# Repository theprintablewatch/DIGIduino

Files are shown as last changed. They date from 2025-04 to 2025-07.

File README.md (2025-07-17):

# The Printable Watch Digital 
Check out [TPW](https://theprintablewatch.com)

Kickstarter Campaign [Kickstarter](https://www.kickstarter.com/projects/theprintablewatch/digiduino-arduino-based-diy-digital-watch-development-kit)

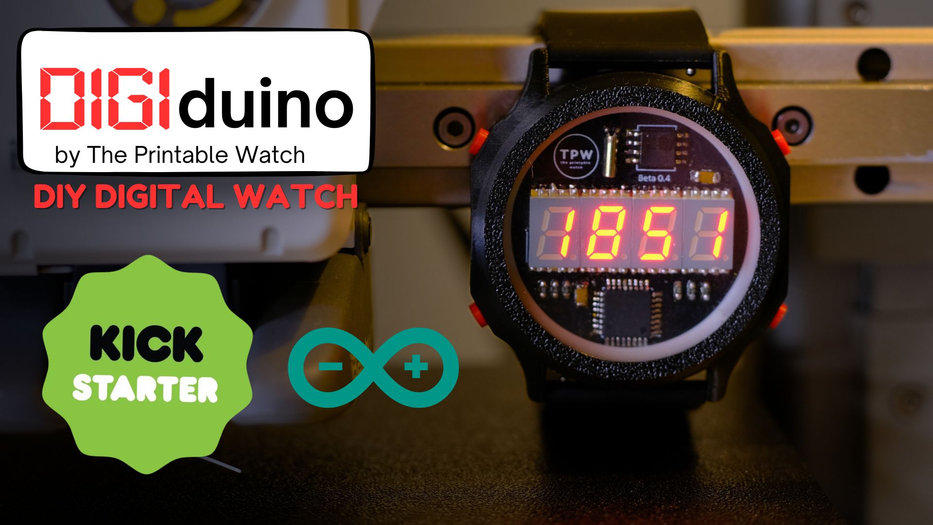
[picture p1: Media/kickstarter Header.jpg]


## Features
  * Arduino based digital watch
    * ATMega328P based
    * DS1302 RTC
    * 4 Digit 7-segment display
    * 4 Programmable physical buttons
  * 3D printed watch case
  * 12 Month+ Battery life

## Arduino Requirements
 * Libraries Used:
   * SevSeg - Dean Reading - https://github.com/DeanIsMe/SevSeg
   * Rtc by Makuna - Michael C. Miller - https://github.com/Makuna/Rtc/wiki
   * MiniCore - MCUdude - https://github.com/MCUdude/MiniCore
      * Add this link to your Boards Manager under Preferences - https://mcudude.github.io/MiniCore/package_MCUdude_MiniCore_index.json

## 3D Printable Case

The case and pushbuttons are designed to be easily 3D printed from any standard 3D printer. I have made the .STEP files available as well as a .dxf of the PCB so you can modify the case or even design your own!
[Download Case Models](https://github.com/theprintablewatch/DIGIduino/tree/main/Models)
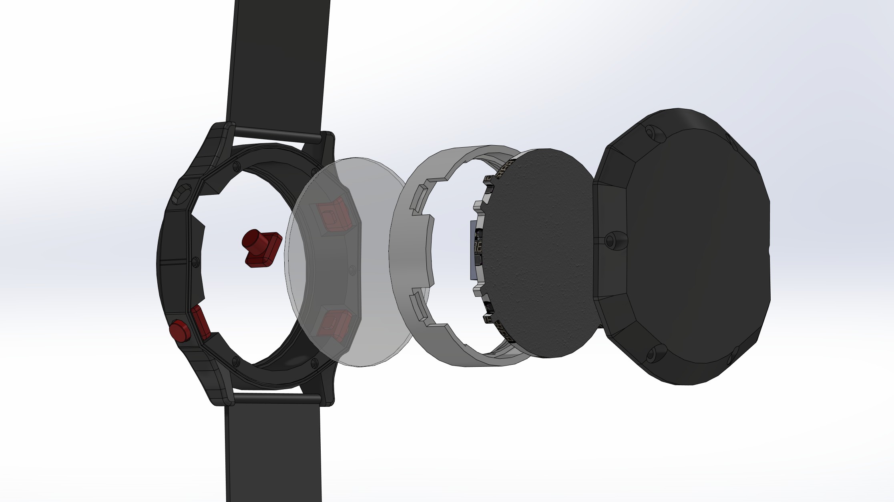
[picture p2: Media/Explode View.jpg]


## How to use the watch?

DIGIduino - How to use the watch? (https://youtu.be/XvohYlr38eU)

## How to Program ATMega328

Follow the guide [here](https://github.com/theprintablewatch/DIGIduino/blob/541a8b5c67f3c3e3cfa8df9d08a5a50cb2cadccd/Programming%20Guide.MD)

I have also filmed a short youtube video explaining how to program a ATMega328 seperate from the Uno more generally.

Minimalist Arduino - How to Program ATmega328 and ATtiny85 (https://youtu.be/qGbuzuVSzVs)

To program the chip on the PCB, follow these steps using the JST Jumper cable

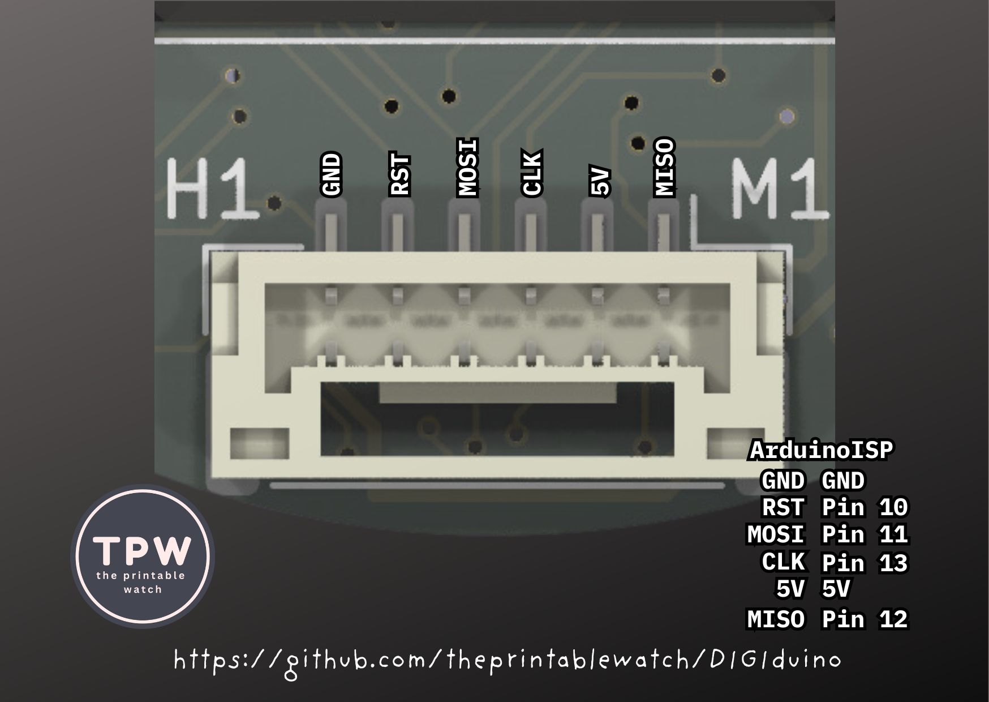
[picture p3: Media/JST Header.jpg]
Back Board


## Developing your own firmware

The DIGIduino firmware is open source, I encourage you to make a copy of the basic firmware and add your own features!
Pins used:

## 🔌 Pin Usage Summary

| **Pin** | **Arduino Alias** | **Function** |
|---|---|---|
| **0** | `D0` | Top Left Button |
| **1** | `D1` | SevSeg digit 0 control |
| **2** | `D2` | Top Right Button (Wake-up button) |
| **3** | `D3` | SevSeg digit 1 control |
| **4** | `D4` | SevSeg digit 2 control |
| **5** | `D5` | SevSeg digit 3 control |
| **6** | `D6` | SevSeg segment A |
| **7** | `D7` | SevSeg segment B |
| **8** | `D8` | SevSeg segment C |
| **9** | `D9` | SevSeg segment D |
| **10**  | `D10` | SevSeg segment E |
| **11**  | `D11` | SevSeg segment F |
| **12**  | `D12` | SevSeg segment G |
| **13**  | `D13` | SevSeg segment DP (decimal point) |
| **14**  | `A0` | RTC Data I/O (`ThreeWire` – DS1302) |
| **15**  | `A1` | RTC CLK (SCLK) |
| **16**  | `A2` | RTC CE (RST) |
| **17**  | `A3` | RTC Power Pin (set HIGH in `isrWake`, LOW in `goToSleep`) |
| **18**  | `A4` | Low Left Button |
| **19**  | `A5` | Low Right Button |
| **20**  | `20` | Spare - Disabled (`pinMode(20, OUTPUT)`) |
| **21**  | `21` | Spare - Disabled (`pinMode(21, OUTPUT)`) |
| **22**  | `22` | Spare - Disabled (`pinMode(22, OUTPUT)`) |

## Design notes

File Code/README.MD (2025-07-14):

Full set-up instructions [here](https://github.com/theprintablewatch/DIGIduino/blob/main/Programming%20Guide.MD)

Before you start, add the MCUdude MiniCore board package to your directories.
File > Preferences - Additional boards manager URLs: > paste this link https://mcudude.github.io/MiniCore/package_MCUdude_MiniCore_index.json

Make sure to follow the programmin
  * SevSeg - Dean Reading
  * Rtc by Makuna - Micheael C. Miller

## Key Features and Libraries

The DIGIduino is an Arduino‑based digital watch built around:
- **ATmega328P** microcontroller
- **DS1302** real‑time clock (RTC)
- **Four-digit seven-segment display**
- **Four control buttons**

### Required Libraries
- [`SevSeg`](https://github.com/DeanIsMe/SevSeg)
- [`Rtc by Makuna`](https://github.com/Makuna/Rtc)

---

## Main Firmware File

The main sketch is located at:

Code/DIGIduinoV1/DIGIduinoV1.ino

The firmware uses a small **state machine** to manage different watch modes:

```c++
// ------------------ State Machine ------------------
enum WatchState {
  NORMAL,
  SHOWDATE,
  SHOWSET,
  TIMESET,
  SHOWDSET,
  DATESET,
  YEARSET,
  UKUSSET,
  SLEEPING
};
```

### Setup Function

The setup() function does the following:
 - Configures button pins
 - Attaches a wake-up interrupt
 - Initializes the seven-segment display
 - Starts the real-time clock
 - Loop and State Machine

The loop() function continuously refreshes the display and switches between states:

```c++
// Refresh the display often
sevseg.refreshDisplay();

// State machine
switch(watchState)
{
  case NORMAL:
    handleNormalMode();
    break;
  case SHOWDATE:
    handleShowDateMode();
    break;
  // ... other cases
  case SLEEPING:
    // Nothing to do while asleep
    break;
}
```

### Example Mode: Normal Operation
handleNormalMode() handles standard time display and input:

```c++
// Time is read once globally to reduce flickering
sevseg.setNumber(timeCombined);

// Check for inactivity → sleep
if(currentMillis - lastInteraction > wakeInterval) {
  goToSleep();
  return;
}

// Handle Spare Pin (enter time-set if held 2s)
checkSparePinHold();
checkHourPinHold();
```

### Sleep and Wake

When idle, the watch enters low power sleep mode:
`pin 17` is the power pin to the RTC, setting this high and low can switch the RTC on and off. Note when the RTC is in sleep it will still keep track of time but it's not possible to set or read the time.

`digitalWrite(17, LOW)` puts the RTC to sleep

```c++
void goToSleep()
{
  // Blank display & reduce power
  sevseg.blank();
  sevseg.refreshDisplay();
  digitalWrite(17, LOW);
  watchState = SLEEPING;

  // Enter AVR power-down mode
  ADCSRA &= ~(1 << 7);
  SMCR |= (1 << 2);
  SMCR |= 1;
  MCUCR |= (3 << 5);
  MCUCR = (MCUCR & ~(1 << 5)) | (1 << 6);
  __asm__ __volatile__("sleep");
}
```

Waking is triggered by a button interrupt:
`digitalWrite(17, HIGH)` Wakes the RTC

```c++
void isrWake()
{
  wakeInterruptTriggered = true;
  digitalWrite(17, HIGH);
  watchState = NORMAL;

  now = Rtc.GetDateTime();
  hour = now.Hour();
  minute = now.Minute();
  day = now.Day();
  month = now.Month();
  year = now.Year();

  lastInteraction = millis();
}
```

## Getting Started

Install the MiniCore board package and required libraries (see README.md and Programming Guide.MD).
Open DIGIduinoV1.ino in the Arduino IDE.
Review the state machine and handlers.
Try modifying handleShowDateMode() or add a new watch mode.
Use HardwareTest/HardwareTest.ino to test buttons and display.

## Firmware Architecture Summary
The firmware is structured with:
Initialization in setup()
A state machine in loop()
Dedicated handler functions for each mode
This clean separation makes it easy to understand and extend. Once you're comfortable with how state transitions and display updates work, you can start adding custom watch features.

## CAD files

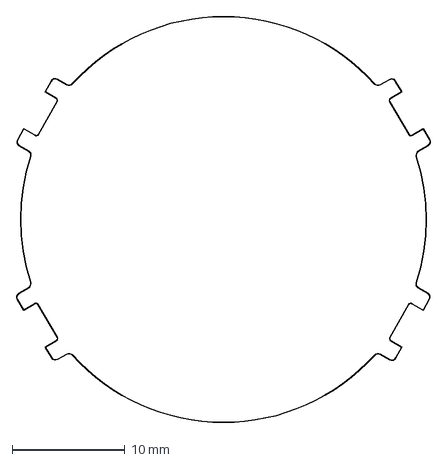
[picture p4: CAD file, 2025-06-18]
Models/PCB Shape2.DXF
36.8 x 36.1 mm

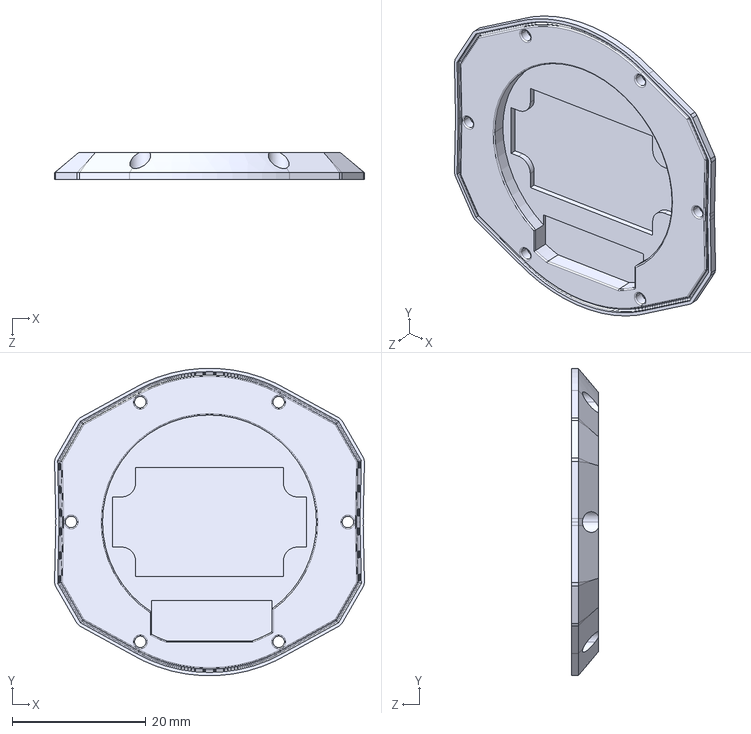
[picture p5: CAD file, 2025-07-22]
Models/VersionA/DigiDuinoV1 Caseback.STEP
46.4 x 45.9 x 4.00 mm

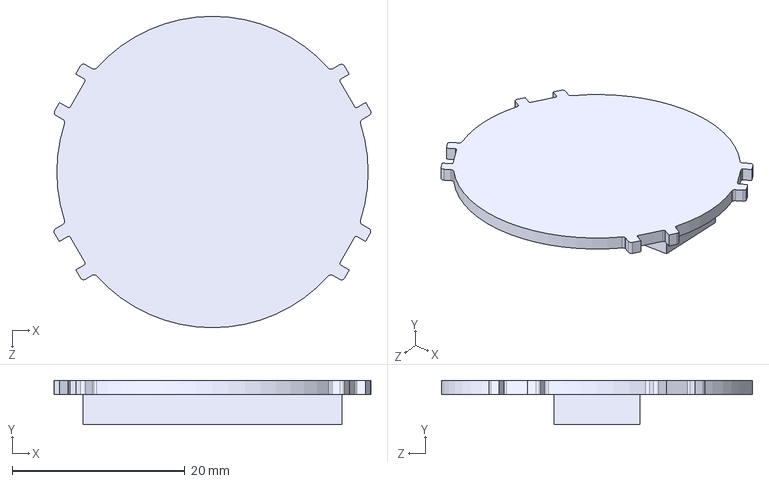
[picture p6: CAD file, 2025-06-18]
Models/PCB Shape.STEP
36.7 x 5.10 x 36.1 mm

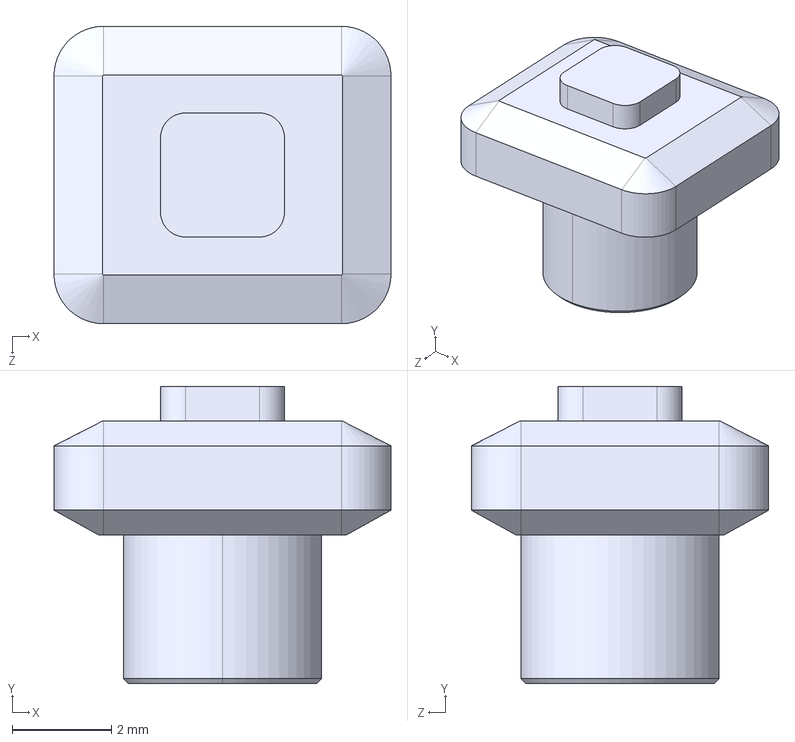
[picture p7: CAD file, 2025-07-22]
Models/VersionA/DigiDuinoV1 Button.STEP
6.80 x 6.00 x 6.00 mm

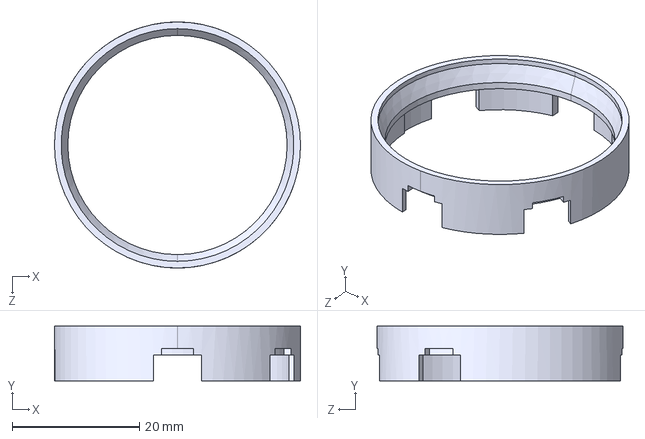
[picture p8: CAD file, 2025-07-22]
Models/VersionA/DigiDuinoV1 Insert Universal.STEP
38.6 x 8.60 x 38.6 mm

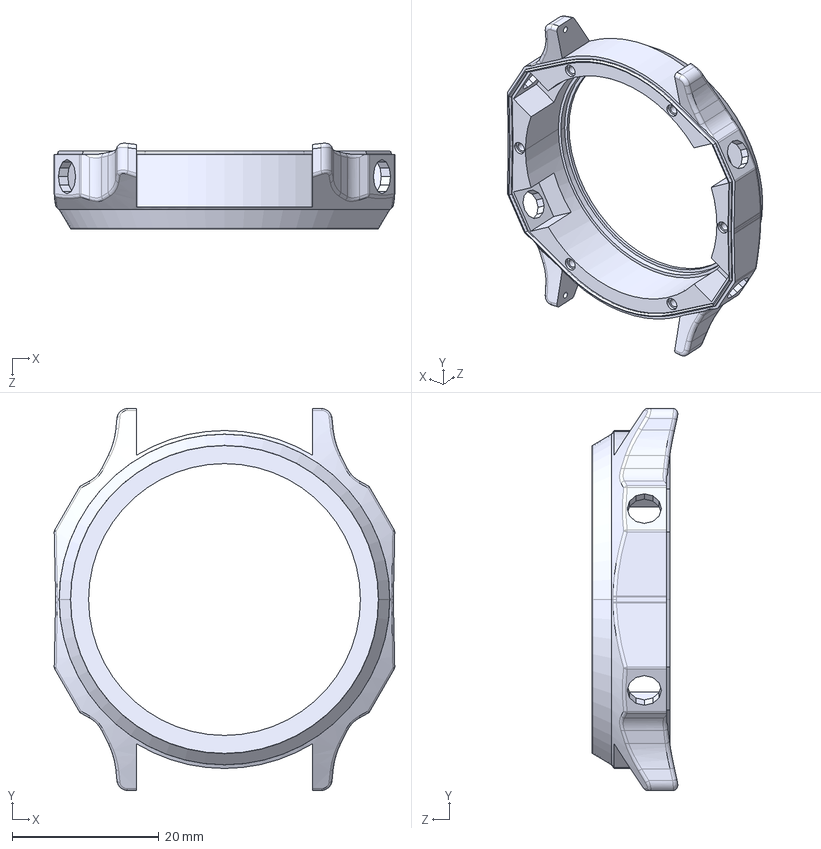
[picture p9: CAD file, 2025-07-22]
Models/VersionA/DigiDuinoV1 Case.STEP
46.4 x 52.0 x 11.7 mm

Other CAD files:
Models/PCB Shape.STL
Models/VersionA/DigiDuinoV1 Button.STL
Models/VersionA/DigiDuinoV1 Case.STL
Models/VersionA/DigiDuinoV1 Caseback.STL
Models/VersionA/DigiDuinoV1 Insert Universal.STL

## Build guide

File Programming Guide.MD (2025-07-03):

# How to program your DIGIduino

### You will need
  * Arduino UNO
  * Programmer Shield 
  * JST Cable
  * Arduino IDE installed on your device

## Step 1

### Arduino IDE setup

Before you start, add the MCUdude MiniCore board package to your directories.
File > Preferences - Additional boards manager URLs: > paste this link https://mcudude.github.io/MiniCore/package_MCUdude_MiniCore_index.json

Then head to Boards Manager, search for MiniCore by MCUdude and install the package.

Now head to library manager and install the following libraries:

  * SevSeg - Dean Reading
  * Rtc by Makuna - Micheael C. Miller

Your IDE is ready to program the DIGIduino.

## Step 2

### Turn your UNO into a programmer

To use your arduino to program other MCUs you need to write a bit of code to it. Luckily, this code is pre-saved in your arduino IDE. 
File > Examples > 11.ArduinoISP > ArduinoISP

If you're using a standard Arduino UNO just upload this to your device without anything connected to it (aside from the USB of course)

Once that's uploaded, your arduino is ready to be used to program the watch! 

## Step 3

### Uploading Code

Open the DIGIduinoV1.ino code

Head to tools> Board > MiniCore > Atmega328

Make sure the rest of the settings under tools are as follows. 

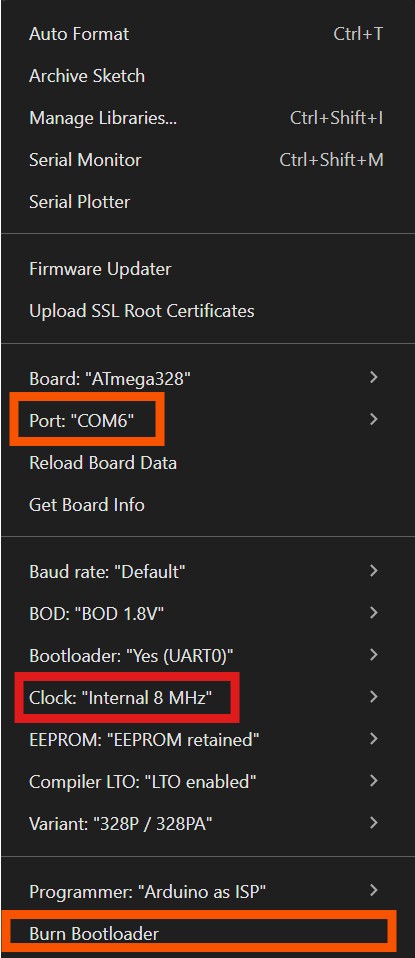
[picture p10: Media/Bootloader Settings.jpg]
Settings


One option which is really important is the Clock setting, MAKE SURE INTERNAL 8MHz is selected. if you burn a bootloader with an external crystal setting you may brick the device.

REMOVE THE BATTERY FROM THE MOVEMENT BEORE PROCEEDING 

Connect the shield to the UNO then plug your DIGIduino to the Shield using the supplied cable.

Your movement will be shipped with the latest main release of the firmware so it will light up. 

You can now edit the sketch for the software and upload to the device. Note, to upload code to external devices (like the movement) you have to use the "Upload Using Programmer" option. Sketch -> Upload Using Programmer. or Ctrl+Shift+U.

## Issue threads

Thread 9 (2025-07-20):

inverted pin mapping on a picture

jblezoray, 2025-07-20:
I think the pins mapping are inverted on this image :

/main/Media/JST%20Header.jpg

The pins may be are rightfully presented if we considered that it is the plate that connects to the arduino.  But the pic suggests it is the watch module connector, therefore they are laterally inverted.

theprintablewatch, 2025-07-20:
The pinout on the back of the movement pcb is the inverse of the one on the shield due to the cable that's supplied. So there is no error. Thanks for checking!

jblezoray, 2025-07-20:
ok thanks. I'm trying to figure out why I can't upload to the watch module :-/

I suspect an issue with my cable ? Is it expected for it to be crossed ?
See the photo bellow of my cable. The arrow points to the red cable, that connects to the right on the watch module connector :

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

Here we can see that the cable is crossed:

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

But from what I see [from the video](https://www.youtube.com/watch?v=eIrj1OmIruk), the cable looks straight.  Here is a screen capture, the arrow points to the red cable. that now connects to the left of the connector of the watch module :

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

If you confirm that it is miswired and should be straight, I can try to rewire it.
Could you check this for me please ?

theprintablewatch, 2025-07-20:
I've just been looking into this. you're correct, the cable needs to be inversed. I'll have to check the batch of cables I've received as they do seem to be wrong.

Do you have the ability to modify the cable. I will be shipping the correct cables in due course.

jblezoray, 2025-07-20:
I confirm you that it works as expected after inverting the cable: I can now upload a soft to the watch module.

theprintablewatch, 2025-07-21:
Thanks for raising this. Sorry about this, I need to investigate how the wrong cables ended up getting sent out and reach out to those affected.
Was modifying the cable easy enough?

jblezoray, 2025-07-21:
No it wasn't easy to modify :-)

The connector housing is not really designed to allow the crimped wires to be extracted.
I did it nonetheless by pushing them out VERY carefully with a needle, but the connector still half broke off.  It still works so that's ok for me.

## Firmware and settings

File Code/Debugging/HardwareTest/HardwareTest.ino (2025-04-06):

/*
  The Printable Watch 2024                                                                                
  theprintablewatch.com
*/

#include "SevSeg.h"
#include "RtcDS1302.h"

//RTC Set UP
ThreeWire myWire(14,15,16); // IO(DATA), SCLK(CLK), CE(RST)
RtcDS1302<ThreeWire> Rtc(myWire);

//SevSeg Startup
SevSeg sevseg; 

const byte BUTTON_PIN = 2;         // Wake up button
const byte BUTTON_HOUR_PIN = 18;    // Button to increment hour
const byte BUTTON_MINUTE_PIN = 19;
const byte BUTTON_SPARE_PIN = 0; 

volatile byte buttonPressed = 0;

int hourPbState = LOW;
int lastHourPbState = LOW;
int minPbState = LOW;
int lastminPbState = LOW;

unsigned long startMillis = 0;  // Stores the last time the timer was checked
const unsigned long interval = 5000; //Display on time in ms
unsigned long currentMillis = millis();


void setup() {
  //SevSeg Setup
  byte numDigits = 4;
  byte digitPins[] = {1, 3, 4, 5};
  byte segmentPins[] = {6, 7, 8, 9, 10, 11, 12, 13}; //changed 11 to 21 for debug
  bool resistorsOnSegments = false; // 'false' means resistors are on digit pins
  byte hardwareConfig = COMMON_CATHODE; // See README.md for options - Changed to match PCB
  bool updateWithDelays = false; // Default 'false' is Recommended
  bool leadingZeros = true; // Use 'true' if you'd like to keep the leading zeros
  bool disableDecPoint = true; // Use 'true' if your decimal point doesn't exist or isn't connected
  
  //Wake Setup
  pinMode(BUTTON_PIN, INPUT); 
  attachInterrupt(digitalPinToInterrupt(BUTTON_PIN), isrButton, FALLING);
  //Hour and Minute Buttons
  pinMode(BUTTON_HOUR_PIN, INPUT);
  pinMode(BUTTON_MINUTE_PIN, INPUT);
  pinMode(BUTTON_SPARE_PIN, INPUT);

  sevseg.begin(hardwareConfig, numDigits, digitPins, segmentPins, resistorsOnSegments, updateWithDelays, leadingZeros, disableDecPoint); // Configuring the display
  sevseg.setBrightness(60); //Adjust if flicking

  Rtc.Begin(); // Start RTC
  RtcDateTime compiled = RtcDateTime(__DATE__, __TIME__);
  currentMillis = millis();
  while(currentMillis - startMillis <= interval) {
  sevseg.setChars("test"); //display TPW on screen
  sevseg.refreshDisplay();

  Rtc.SetDateTime(compiled);

  }
  
}

void loop() {

RtcDateTime now = Rtc.GetDateTime(); //Get the time from RTC

int sec = now.Second(); //Get Hour
int minute = now.Minute(); // Get Minute
int timeCombined = (minute * 100) + sec;


sec = now.Second(); //Get Hour
minute = now.Minute(); // Get Minute
timeCombined = (minute * 100) + sec;
sevseg.setNumber(timeCombined, 1);
sevseg.refreshDisplay(); // Must run repeatedlyd


while(digitalRead(BUTTON_PIN)==1)
{
 sevseg.setNumber(1111);
sevseg.refreshDisplay(); 
}


while(digitalRead(BUTTON_HOUR_PIN)==1)
{
 sevseg.setNumber(2222);
sevseg.refreshDisplay(); 
}


while(digitalRead(BUTTON_MINUTE_PIN)==1)
{
 sevseg.setNumber(3333);
sevseg.refreshDisplay(); 
}

while(digitalRead(BUTTON_SPARE_PIN)==1)
{
 sevseg.setNumber(4444);
sevseg.refreshDisplay(); 
}


  /////////////////////////////// 
 //           CLOCK           //
///////////////////////////////
/*
RtcDateTime now = Rtc.GetDateTime(); //Get the time from RTC


currentMillis = millis();

int hour = now.Hour(); //Get Hour
int minute = now.Minute(); // Get Minute
int timeCombined = (hour * 100) + minute;
  ////////////////////////////////////////////////////////// 
 //            Hour and Min setting functions            //
//////////////////////////////////////////////////////////


while(currentMillis - startMillis < interval)
{

currentMillis = millis();
 //formats the time for the display
 RtcDateTime now = Rtc.GetDateTime(); //Get the time from RTC
hour = now.Hour(); //Get Hour
minute = now.Minute(); // Get Minute
timeCombined = (hour * 100) + minute;
sevseg.setNumber(timeCombined, 1);
sevseg.refreshDisplay(); // Must run repeatedlyd


//Time Setting Function
minPbState = digitalRead(BUTTON_MINUTE_PIN);
if(minPbState == LOW && lastminPbState == HIGH){
minute = (minute + 1) % 60; // Increment hour by one per click
Rtc.SetDateTime(RtcDateTime(now.Year(), now.Month(), now.Day(), hour, minute, now.Second()));
timeCombined = (hour * 100) + minute;
}
lastminPbState = minPbState;

hourPbState = digitalRead(BUTTON_HOUR_PIN);
if(hourPbState == LOW && lastHourPbState == HIGH){
hour = (hour + 1) % 24; // Increment hour by one per click
Rtc.SetDateTime(RtcDateTime(now.Year(), now.Month(), now.Day(), hour, minute, now.Second()));
timeCombined = (hour * 100) + minute;
}
lastHourPbState = hourPbState;

}




  ////////////////////////////////////////// 
 //            SLEEP FUNCTION            //
//////////////////////////////////////////
if (currentMillis - startMillis >= interval) {
sevseg.blank(); // Clear the screen before sleeping
sevseg.refreshDisplay();
//LowPower.idle(SLEEP_FOREVER, ADC_OFF, TIMER2_OFF, TIMER1_OFF, TIMER0_OFF, SPI_OFF, USART0_OFF, TWI_OFF);
ADCSRA &= ~(1 << 7);
SMCR |= (1 <<2);
SMCR |= 1;

MCUCR |= (3 <<5);
MCUCR = (MCUCR & ~(1 <<5)) | (1 << 6);
__asm__ __volatile__("sleep");

}
*/
}




//Interupt for wake button
void isrButton()
{
  buttonPressed = 1;
  sevseg.setBrightness(100);
  startMillis = millis(); //starts timer for display on
}

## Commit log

2025-05-08 added year change, and battery monitor
2025-06-30 Rename R (148 x 105 mm).jpg to JST Header.jpg
2025-07-03 STL files added
    [DigiDuinoV1 Button.STL, DigiDuinoV1 Case.STL, DigiDuinoV1 Caseback.STL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]
2025-07-22 updated folder layout
    [DigiDuinoV1 Button.STEP, DigiDuinoV1 Button.STL, DigiDuinoV1 Case.STEP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]
2025-07-22 advanced button management
2025-07-22 repeated event when pressing buttons
